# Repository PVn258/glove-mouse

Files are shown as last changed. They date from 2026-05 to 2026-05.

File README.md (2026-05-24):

# Glove Mouse

A wearable BLE HID mouse built on the **XIAO ESP32-C6**, controlled by wrist movement (MPU-6050 gyroscope) and finger sensors (flex + FSR pressure).

---

## Hardware

| Component | Role |
|---|---|
| XIAO ESP32-C6 | Main MCU + BLE |
| MPU-6050 | Gyroscope / accelerometer → cursor movement |
| Flex sensor | Thumb bend → toggle transmission mode |
| FSR (×2) | Left / right click |
| MT3608 boost | Battery → ~4.6 V rail for VIN |
| LM339 (×2) | Analog comparators for flex & FSR digital output |

### Wiring

```
MPU-6050   SDA → GPIO 6   |   SCL → GPIO 7
Flex  DO       → GPIO 4     (thumb bend = transmit mode)
FSR Left  DO   → GPIO 2     (left click)
FSR Right DO   → GPIO 3     (right click)
```

---

## Firmware

### Dependencies (install via Arduino IDE Library Manager)

- **NimBLE-Arduino** by h2zero `≥ 1.4.0`
- **MPU6050** by Electronic Cats

### Board setup

1. Add ESP32 board package URL in Arduino IDE preferences:
   ```
   https://raw.githubusercontent.com/espressif/arduino-esp32/gh-pages/package_esp32_index.json
   ```
2. Install **esp32** by Espressif Systems
3. Select board: **XIAO ESP32C6**

### Usage

1. Flash `glove_mouse/glove_mouse.ino`
2. Open Serial Monitor at **115200 baud**
3. Pair with **"Glove Mouse"** from your host's Bluetooth settings
4. **Bend thumb** → transmission mode (cursor follows wrist, FSR triggers clicks)
5. **Release thumb** → sleep mode (all input paused)

### Tuning parameters

| Constant | Default | Description |
|---|---|---|
| `MAX_MOVE` | 20 | Max pixels per frame (higher = more sensitive) |
| `MAX_DPS` | 200 | Gyro threshold for full speed (°/s) |
| `DEADZONE` | 5 | Dead zone in °/s (higher = less jitter) |
| `CURVE_EXP` | 1.5 | Speed curve exponent (1.0 = linear, >1 = precise low / fast high) |
| `EMA_ALPHA` | 0.25 | Smoothing factor (0.1 = very smooth, 0.4 = responsive) |

---

## Schematic & PCB Design

The circuit was drawn in **EasyEDA Pro** and exported for JLCPCB fabrication.

| File | Description |
|---|---|
| `hardware/ProPrj_Seeed Studio XIAO ESP32C6_2026-05-12_10-11-10_2026-05-13.epro2` | EasyEDA Pro project (editable source) |
| `hardware/SCH_Schematic1_2026-05-14.pdf` | Schematic PDF (quick reference) |

**PCB specs for JLCPCB ordering:**

| Parameter | Value |
|---|---|
| Layers | 2 |
| Board size | 50 × 40 mm |
| Min trace / space | 0.2 mm / 0.2 mm |
| Min via drill | 0.4 mm |
| Surface finish | HASL (lead-free) |

---

## Repository Structure

```
glove_mouse/
└── glove_mouse.ino          Main BLE HID firmware

hardware/
├── *.epro2                  EasyEDA Pro schematic & PCB project
└── *.pdf                    Exported schematic PDF

tests/
├── all_sensors_test/        All sensors combined diagnostic
├── flex_sensor_test/        Flex sensor digital output test
├── mpu6050_test/            MPU-6050 I2C + gyro/accel readout
└── pressure_sensor_test/    FSR pressure sensor test
```

---

## Running the Tests

Each folder under `tests/` is a standalone Arduino sketch.  
Open the `.ino` file in Arduino IDE, select **XIAO ESP32C6**, upload, then open Serial Monitor at **115200 baud**.

| Sketch | What it prints |
|---|---|
| `mpu6050_test` | Accel XYZ + Gyro XYZ raw values |
| `flex_sensor_test` | Digital output of flex comparator (0/1) |
| `pressure_sensor_test` | Digital output of left & right FSR (0/1) |
| `all_sensors_test` | All of the above combined |

---

## License

MIT

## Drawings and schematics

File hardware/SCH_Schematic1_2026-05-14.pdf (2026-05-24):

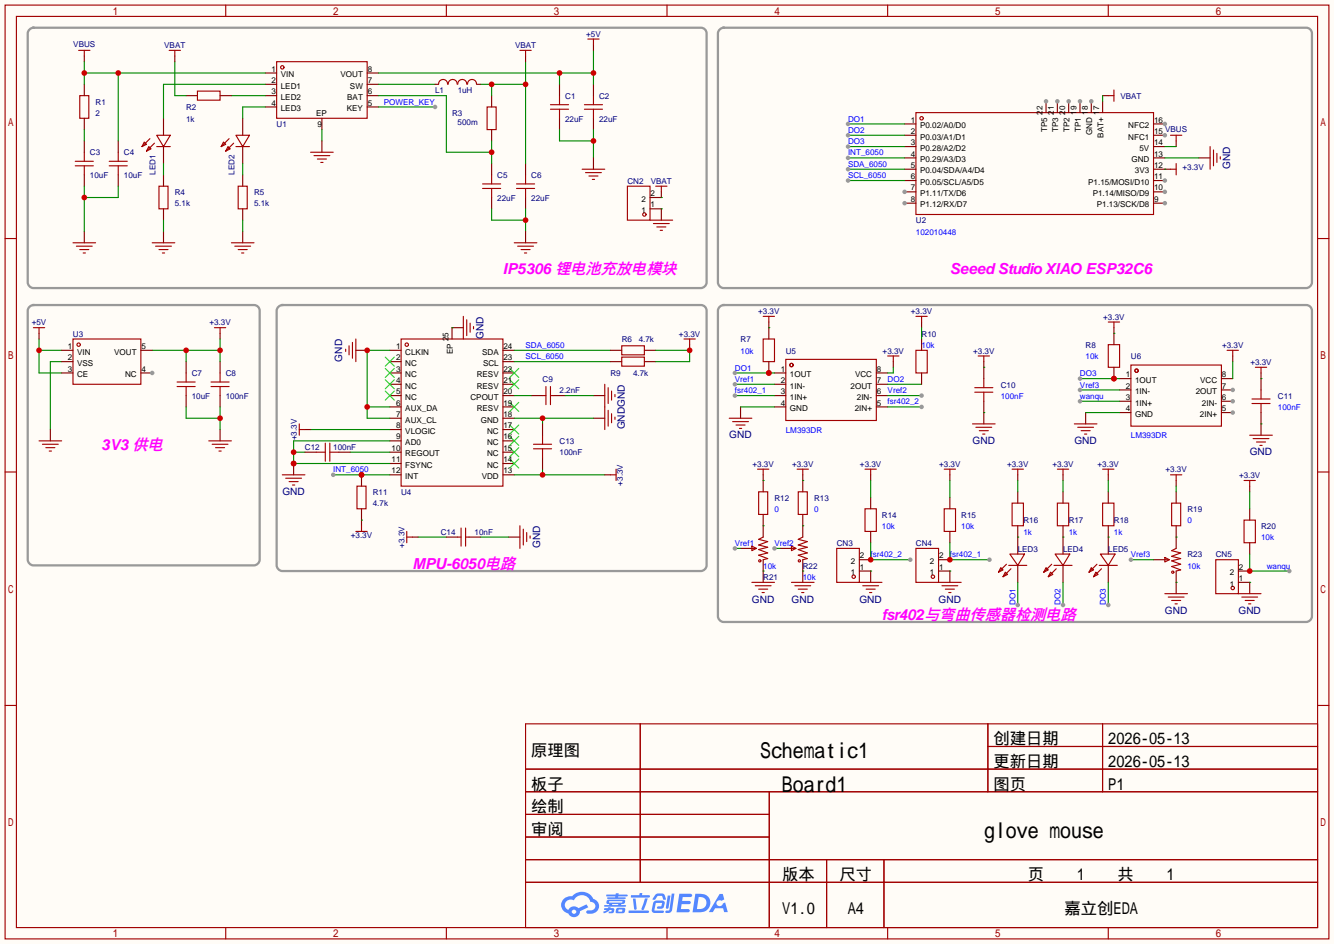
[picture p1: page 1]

P1.14/MISO/D9 10 P1.15/MOSI/D10 11 3V3 12 GND 13 5V 14 NFC1 15 NFC2 16 BAT+ 17 GND ¹⁸

原理图 | Schematic1 | 创建日期 | 2026-05-13

更新日期 | 2026-05-13

板子 | Board1 | 图页 | P1
绘制 | | glove mouse
审阅

V1.0 | A4 | 嘉立创EDA

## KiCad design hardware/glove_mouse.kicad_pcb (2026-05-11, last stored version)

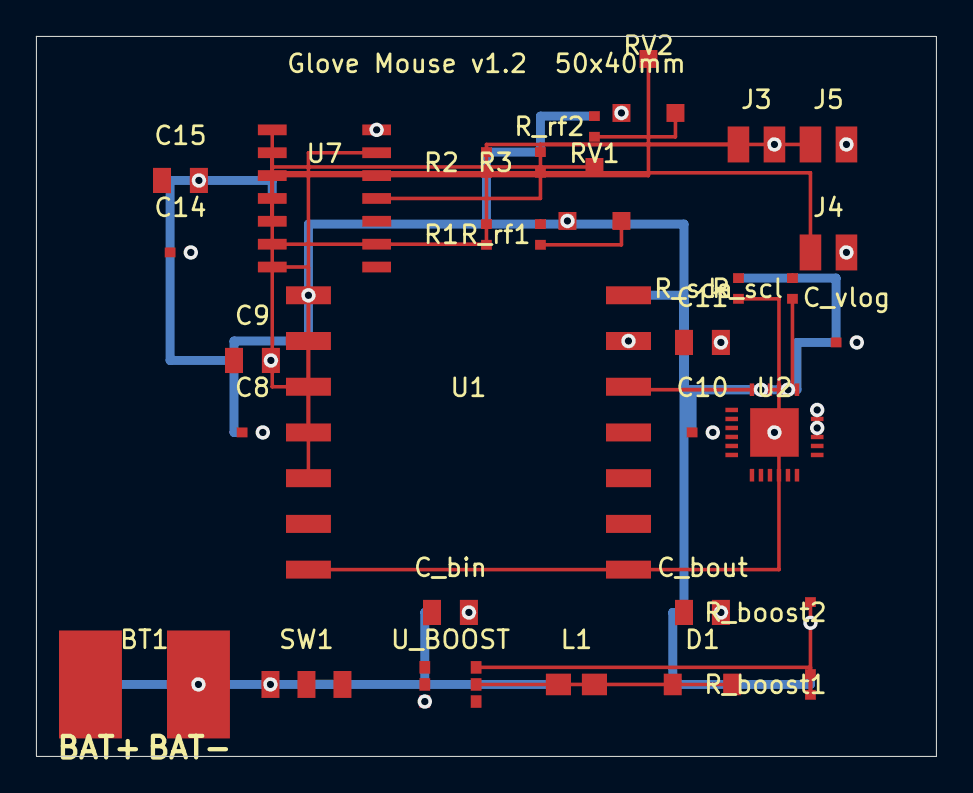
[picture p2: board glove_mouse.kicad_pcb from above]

Board: 2 copper layers, 50.0 x 40.0 mm, 31 parts (0 on the bottom side), 19 nets.

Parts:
BT1: LiPo Battery; BAT-SOLDER
C8, C10, C14: 100nF; C_0402
C9: 22uF; C_0805
C11: 10uF; C_0805
C15: 4.7uF; C_0805
C_bin: 10uF; C_0805
C_bout: 22uF; C_0805
C_vlog: 100nF; C_0402
D1: SS14; SOD-123
J3: Flex; JST-PH-2P
J4: FSR Left; JST-PH-2P
J5: FSR Right; JST-PH-2P
L1: 4.7uH; L_0603
R1: 47k; R_0402
R2, R3: 10k; R_0402
RV1, RV2: 10k Trim; TRIMPOT-3224W
R_boost1: 100k; R_0402
R_boost2: 15k; R_0402
R_rf1, R_rf2: 10k; R_0402
R_scl: 4.7k; R_0402
R_sda: 4.7k; R_0402
SW1: Power SW; SLIDE-SW
U1: XIAO ESP32C6; XIAO-ESP32C6
U2: MPU-6050; QFN-24
U7: LM339; SOP-14
U_BOOST: MT3608; SOT-23-6

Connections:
3V3: C8.1, C9.1, C10.1, C11.1, C14.1, C15.1, C_vlog.1, R1.1, R2.1, R3.1, R_rf1.1, R_rf2.1, R_scl.1, R_sda.1, U1.2, U2.1, U2.6, U7.4
BAT_RAW: BT1.+, SW1.3
BOOST_FB: R_boost1.2, R_boost2.1, U_BOOST.4
BOOST_OUT: C_bout.1, D1.K, R_boost1.1, U1.8
BOOST_SW: D1.A, L1.2, U_BOOST.5
FLEX_DO: U1.5, U7.1
FSR_L_DO: U1.3, U7.7
FSR_R_DO: U1.4, U7.9
GND: BT1.-, C8.2, C9.2, C10.2, C11.2, C14.2, C15.2, C_bin.2, C_bout.2, C_vlog.2, J3.2, J4.2, J5.2, RV1.1, RV2.1, R_boost2.2, SW1.1, U1.1, U1.9, U2.2, U2.5, U2.7, U2.9, U2.25, U7.8, U_BOOST.1
SCL: R_scl.2, U1.10, U2.3
SDA: R_sda.2, U1.7, U2.4
VBAT: C_bin.1, L1.1, SW1.2, U_BOOST.2, U_BOOST.3
VMID_FLEX: J3.1, R1.2, U7.2
VMID_FSR_L: J4.1, R2.2, U7.5
VMID_FSR_R: J5.1, R3.2, U7.11
VREF_FLEX: RV1.W, U7.3
VREF_FLEX_PRE: RV1.3, R_rf1.2
VREF_FSR: RV2.W, U7.6, U7.10
VREF_FSR_PRE: RV2.3, R_rf2.2

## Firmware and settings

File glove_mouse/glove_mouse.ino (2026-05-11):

/*
 * Glove Mouse — BLE HID 鼠标固件
 * 硬件：ESP32C6
 *
 * 接线：
 *   MPU-6050  SDA → GPIO 6  |  SCL → GPIO 7
 *   Flex  DO  → GPIO 4        (拇指弯曲 → 传输模式)
 *   FSR 左DO  → GPIO 2        (左键)
 *   FSR 右DO  → GPIO 3        (右键)
 *
 * 依赖库（Arduino IDE 库管理器安装）：
 *   · NimBLE-Arduino  by h2zero      ≥ 1.4.0
 *   · MPU6050         by Electronic Cats
 *
 * 使用方法：
 *   1. 上传固件，打开串口监视器 (115200 baud)
 *   2. 主机蓝牙搜索并配对 "Glove Mouse"
 *   3. 弯曲拇指 → 传输模式 (光标跟随手腕移动，FSR 触发点击)
 *   4. 松开拇指 → 休眠模式 (停止所有输入)
 *
 * 调参说明：
 *   MAX_MOVE     最大每帧像素（满速时输出，调大更灵敏）
 *   MAX_DPS      对应满速的陀螺仪角速度阈值
 *   DEADZONE     °/s 死区（调大抗手抖，调小响应快）
 *   CURVE_EXP    曲线指数：1.0=线性，>1=低速精准/高速快
 *   EMA_ALPHA    平滑系数：0.1=极平滑，0.4=响应快
 */

#include <Wire.h>
#include <MPU6050.h>
#include <NimBLEDevice.h>
#include <NimBLEServer.h>
#include <NimBLEHIDDevice.h>
#include <HIDTypes.h>

// ── 引脚定义（Seeed XIAO ESP32C6）────────────────────────────
#define SDA_PIN          6
#define SCL_PIN          7
#define PIN_FLEX_DO      17
#define PIN_FSR_LEFT_DO  23
#define PIN_FSR_RIGHT_DO 16

// ── 陀螺仪参数 ────────────────────────────────────────────────
#define GYRO_LSB      131.0f   // ±250°/s 量程对应 LSB 系数
#define DEADZONE      3.0f     // °/s 死区（低于此值=静止）
#define MAX_DPS       80.0f   // °/s，Y轴（俯仰）满速阈值
#define MAX_DPS_X     80.0f   // °/s，X轴（偏航）满速阈值
#define MAX_MOVE      32       // 满速时每帧最大像素位移（X轴）
#define MAX_MOVE_Y    18       // Y轴（上下）满速像素
#define RIGHT_BOOST   1.6f     // X轴向右的额外增益（>1 = 更容易向右）
#define CURVE_EXP     1.4f     // 曲线指数，必须 >1：低速精准/高速快速
                               //   >1 = 凹曲线：10%速→6%输出（精准）
                               //   <1 = 凸曲线：10%速→40%输出（抖动）
#define EMA_ALPHA     0.20f    // EMA 平滑系数（0~1，越小越平滑）

// ── 防抖参数 ──────────────────────────────────────────────────
#define DEBOUNCE_MS   40       // 与传感器测试保持一致

// ── HID 报表描述符（3 按键鼠标 + 相对 X/Y） ──────────────────
// Report ID 1: buttons(1B) + x(1B) + y(1B) = 3 字节
static const uint8_t reportMap[] = {
    USAGE_PAGE(1),       0x01,  // Generic Desktop
    USAGE(1),            0x02,  // Mouse
    COLLECTION(1),       0x01,  // Application
      REPORT_ID(1),      0x01,  //   Report ID = 1
      USAGE(1),          0x01,  //   Pointer
      COLLECTION(1),     0x00,  //   Physical

        // ── 按键：3 位有效 + 5 位填充 ────────────────
        USAGE_PAGE(1),   0x09,  //     Button Page
        USAGE_MINIMUM(1),0x01,  //     Button 1 (左键)
        USAGE_MAXIMUM(1),0x03,  //     Button 3 (中键)
        LOGICAL_MINIMUM(1),0x00,
        LOGICAL_MAXIMUM(1),0x01,
        REPORT_COUNT(1), 0x03,  //     3 按键位
        REPORT_SIZE(1),  0x01,
        HIDINPUT(1),     0x02,  //     Data, Var, Abs
        REPORT_COUNT(1), 0x01,  //     5 位填充
        REPORT_SIZE(1),  0x05,
        HIDINPUT(1),     0x03,  //     Const

        // ── X / Y 相对移动 ────────────────────────────
        USAGE_PAGE(1),   0x01,  //     Generic Desktop
        USAGE(1),        0x30,  //     X
        USAGE(1),        0x31,  //     Y
        LOGICAL_MINIMUM(1),0x81,// -127
        LOGICAL_MAXIMUM(1),0x7F,//  127
        REPORT_SIZE(1),  0x08,
        REPORT_COUNT(1), 0x02,
        HIDINPUT(1),     0x06,  //     Data, Var, Rel

      END_COLLECTION(0),
    END_COLLECTION(0)
};

// ── 全局对象 ──────────────────────────────────────────────────
MPU6050                mpu;
NimBLEServer*          bleServer    = nullptr;
NimBLEHIDDevice*       hidDevice    = nullptr;
NimBLECharacteristic*  inputReport  = nullptr;
volatile bool          bleConnected = false;

// ── Flex 防抖状态（40ms，模式切换用） ────────────────────────
bool     last_flex  = false;
uint32_t flex_ts    = 0;
bool     flex_active = false;
bool     prev_flex_active = false;

// ── 按键状态 ──────────────────────────────────────────────────
// 非对称防抖：按下立即响应，松开需稳定 LEFT_RELEASE_MS 才确认
// 解决 FSR 持续按压时信号抖动导致长按被误判为多次单击的问题
#define LEFT_RELEASE_MS  2   // 左键松开防抖（ms）；短于此的"抬起"视为抖动忽略
#define BTN_DEBOUNCE_MS  1    // 右键双向防抖时间
bool     last_raw_right = false;
uint32_t left_release_ts = 0,  right_db_ts = 0;
bool     deb_left   = false, deb_right  = false;
uint8_t  last_sent_buttons = 0;
bool     btn_dirty  = false;  // 按键状态已变，等待随下一帧发出

// ── EMA 平滑状态（进入传输模式时重置） ──────────────────────
float    ema_x = 0.0f, ema_y = 0.0f;

// ── 发送限速 ─────────────────────────────────────────────────
#define REPORT_INTERVAL_MS  16   // 移动报告 ~60Hz；与 20ms 连接间隔匹配，不积压队列
#define SERIAL_INTERVAL_MS  150  // 串口调试每 150ms 一次
uint32_t last_report_ms = 0;
uint32_t last_serial_ms = 0;

// ─────────────────────────────────────────────────────────────
//  BLE 连接回调
// ─────────────────────────────────────────────────────────────
class MyServerCallbacks : public NimBLEServerCallbacks {
    void onConnect(NimBLEServer* server, NimBLEConnInfo& connInfo) override {
        bleConnected = true;
        // 请求 20-30ms 连接间隔（16-24×1.25ms）
        // 不要请求 7.5ms：Windows 会在 30-60s 后强制重协商 → 重协商期间断流积压 → 卡顿
        // 20ms 是 Windows HID 电源策略的舒适区，不会触发重协商
        server->updateConnParams(connInfo.getConnHandle(), 16, 24, 0, 300);
        Serial.println("[BLE] 已连接！");
    }
    void onDisconnect(NimBLEServer* server, NimBLEConnInfo& connInfo, int reason) override {
        bleConnected = false;
        Serial.println("[BLE] 连接断开，重新广播...");
        server->startAdvertising();
    }
};

// ─────────────────────────────────────────────────────────────
//  工具函数
// ─────────────────────────────────────────────────────────────

// 软件防抖（40ms 稳定确认，与 all_sensors_test 完全一致）
bool debounce(bool raw, bool& last, bool& confirmed, uint32_t& ts) {
    if (raw != last) { last = raw; ts = millis(); }
    if ((millis() - ts) >= DEBOUNCE_MS && raw != confirmed) {
        confirmed = raw;
        return true;
    }
    return false;
}

// 非线性曲线映射：死区→幂次曲线→截断
//   rightBoost：仅对正方向（向右）额外乘以增益，默认 1.0（不增益）
int8_t curveMap(float dps, float maxOut = MAX_MOVE, float maxDps = MAX_DPS,
                float rightBoost = 1.0f) {
    float abs_dps = fabsf(dps);
    if (abs_dps < DEADZONE) return 0;
    float norm = (abs_dps - DEADZONE) / (maxDps - DEADZONE);
    if (norm > 1.0f) norm = 1.0f;
    float output = powf(norm, CURVE_EXP) * maxOut;
    if (dps > 0.0f) {
        output *= rightBoost;
        if (output > 127.0f) output = 127.0f;
        return (int8_t)output;
    }
    return (int8_t)(-output);
}

// 发送 HID 鼠标报告（3 字节：按键 + dX + dY）
// notify(data, len) 直接发送：队列满时丢弃当前帧而非阻塞 loop()
void sendMouseReport(uint8_t buttons, int8_t dx, int8_t dy) {
    if (!bleConnected || inputReport == nullptr) return;
    uint8_t report[3] = { buttons, (uint8_t)dx, (uint8_t)dy };
    inputReport->notify(report, sizeof(report));
}

// ─────────────────────────────────────────────────────────────
//  BLE HID 初始化
// ─────────────────────────────────────────────────────────────
void initBLE() {
    NimBLEDevice::init("Glove Mouse");
    NimBLEDevice::setSecurityAuth(true, true, true);
    NimBLEDevice::setSecurityIOCap(BLE_HS_IO_NO_INPUT_OUTPUT);

    bleServer = NimBLEDevice::createServer();
    bleServer->setCallbacks(new MyServerCallbacks());

    hidDevice   = new NimBLEHIDDevice(bleServer);
    inputReport = hidDevice->getInputReport(1);        // Report ID = 1

    hidDevice->setManufacturer("ESP32C6-Glove");
    hidDevice->setHidInfo(0x00, 0x01);                 // Country=0, Flags=NormallyConnectable

    hidDevice->setReportMap((uint8_t*)reportMap, sizeof(reportMap));
    hidDevice->startServices();

    NimBLEAdvertising* adv = bleServer->getAdvertising();
    adv->setAppearance(HID_MOUSE);
    adv->addServiceUUID(hidDevice->getHidService()->getUUID());
    adv->start();

    Serial.println("[BLE] 广播中... 请在主机蓝牙中搜索 \"Glove Mouse\"");
}

// ─────────────────────────────────────────────────────────────
//  setup
// ─────────────────────────────────────────────────────────────
void setup() {
    Serial.begin(115200);
    delay(500);

    // GPIO 初始化
    // FSR/Flex 比较器 DO 为开漏输出：按下主动拉低，不按时高阻抗
    // 必须启用内部上拉，否则拔掉 USB 后引脚浮空，随机触发按键
    pinMode(PIN_FLEX_DO,      INPUT_PULLUP);
    pinMode(PIN_FSR_LEFT_DO,  INPUT_PULLUP);
    pinMode(PIN_FSR_RIGHT_DO, INPUT_PULLUP);

    // MPU-6050 初始化（400kHz 快速模式，减少 I2C 阻塞时间）
    Wire.begin(SDA_PIN, SCL_PIN);
    Wire.setClock(400000);
    mpu.initialize();
    if (!mpu.testConnection()) {
        Serial.println("[ERR] MPU-6050 连接失败！检查 SDA/SCL 接线后重启。");
        while (true) delay(1000);
    }
    Serial.println("[OK]  MPU-6050 就绪");

    // BLE HID 初始化
    initBLE();

    Serial.println("=== Glove Mouse 固件就绪 ===");
    Serial.println("弯曲拇指 → 传输模式 | 松开拇指 → 休眠模式");
    Serial.println("---");
}

// ─────────────────────────────────────────────────────────────
//  loop  (100 Hz)
// ─────────────────────────────────────────────────────────────
void loop() {
    uint32_t now = millis();

    // ── 1. 读取传感器 ────────────────────────────────────────
    bool raw_flex  = (digitalRead(PIN_FLEX_DO)      == LOW);
    bool raw_left  = (digitalRead(PIN_FSR_LEFT_DO)  == LOW);
    bool raw_right = (digitalRead(PIN_FSR_RIGHT_DO) == LOW);

    // ── 2. Flex 防抖（40ms，仅用于模式切换） ─────────────────
    debounce(raw_flex, last_flex, flex_active, flex_ts);

    // ── 3. 按键通道（与 flex 完全独立） ──────────────────────────
    // 左键：非对称防抖
    //   按下 → 立即确认（不错过点击）
    //   松开 → 需稳定 LEFT_RELEASE_MS 才确认（忽略持续按压中的短暂抖动）
    if (raw_left) {
        deb_left = true;           // 按下：立即
        left_release_ts = 0;       // 重置松开计时
    } else if (deb_left) {         // 原本是按下，现在信号消失
        if (left_release_ts == 0) left_release_ts = now;
        if (now - left_release_ts >= LEFT_RELEASE_MS) deb_left = false;
    }

    // 右键：1ms 双向防抖
    if (raw_right != last_raw_right){ last_raw_right = raw_right; right_db_ts = now; }
    if ((now - right_db_ts) >= BTN_DEBOUNCE_MS) deb_right = raw_right;

    uint8_t buttons = (deb_left ? 0x01 : 0x00) | (deb_right ? 0x02 : 0x00);
    if (buttons != last_sent_buttons) {
        last_sent_buttons = buttons;
        btn_dirty = true;   // 标记待发，不立即发——避免用 0,0 打断正在进行的移动
    }

    // ── 4. 传输模式：陀螺仪移动（独立限速） ──────────────────
    if (flex_active) {
        if (!prev_flex_active) { ema_x = 0.0f; ema_y = 0.0f; }  // 入场重置

        if (now - last_report_ms >= REPORT_INTERVAL_MS) {
            // 断流保护：若距上次发送超 80ms（重连/干扰后），重置 EMA 并跳过本帧
            // 避免积压的陈旧运动数据在恢复时一次性涌出导致主机卡顿
            if (now - last_report_ms > 80) {
                ema_x = 0.0f; ema_y = 0.0f;
                last_report_ms = now;
                prev_flex_active = flex_active;
                return;
            }
            last_report_ms = now;

            int16_t ax, ay, az, gx, gy, gz;
            mpu.getMotion6(&ax, &ay, &az, &gx, &gy, &gz);

            float combined_x = (gy - gz) / GYRO_LSB;  // 小臂旋转 + 手腕侧弯
            float gx_dps     = gx / GYRO_LSB;

            ema_x = EMA_ALPHA * combined_x + (1.0f - EMA_ALPHA) * ema_x;
            ema_y = EMA_ALPHA * gx_dps     + (1.0f - EMA_ALPHA) * ema_y;

            int8_t mx = curveMap(-ema_x, MAX_MOVE,   MAX_DPS_X, RIGHT_BOOST);
            int8_t my = curveMap(-ema_y, MAX_MOVE_Y, MAX_DPS);

            // 有移动 或 按键状态待发 → 合并进同一帧，消除按键触发时的移动停顿
            if (mx || my || btn_dirty) {
                sendMouseReport(last_sent_buttons, mx, my);
                btn_dirty = false;
            }

            // 串口调试（Serial.printf 在此处调用，已在 BLE 发送之后，不影响发送时序）
            if (now - last_serial_ms >= SERIAL_INTERVAL_MS) {
                last_serial_ms = now;
                Serial.printf("[传输] 左:%s 右:%s | dX:%4d dY:%4d\n",
                    deb_left ? "▼" : "○", deb_right ? "▼" : "○",
                    (int)mx, (int)my);
            }
        }
    }

    // ── 5. 非传输模式下：若按键状态待发则立即发（无移动帧可搭载） ──
    if (!flex_active && btn_dirty) {
        sendMouseReport(last_sent_buttons, 0, 0);
        btn_dirty = false;
    }

    // ── 6. 模式切换：退出传输时发一次零移动确保干净 ──────────
    if (prev_flex_active && !flex_active) {
        sendMouseReport(last_sent_buttons, 0, 0);
        Serial.println("[休眠]");
    }

    prev_flex_active = flex_active;
}

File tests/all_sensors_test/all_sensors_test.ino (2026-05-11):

/*
 * 三传感器综合测试草图
 *
 * 在不连接蓝牙主机的情况下，验证所有传感器读数和状态逻辑正确。
 * 所有引脚、极性、防抖逻辑与主程序 glove_mouse.ino 完全同步。
 *
 * 接线汇总（与主程序一致）：
 *   MPU-6050  SDA → GPIO 0  |  SCL → GPIO 1
 *   Flex DO   → GPIO 17
 *   FSR 左DO  → GPIO 23  |  FSR 右DO → GPIO 16
 *
 * 依赖库：MPU6050 by Electronic Cats
 *
 * Serial Monitor 输出示例：
 *   [传输] 左:[按下] 右:[----] | dX:  12 dY:  -3  (EMA X: 8.2  Y:-2.1)
 *   [休眠] 左:[----] 右:[----] | 静止
 */

#include <Wire.h>
#include <MPU6050.h>

// ── 引脚定义（与主程序完全一致） ──────────────────────────────
#define SDA_PIN          0
#define SCL_PIN          1
#define PIN_FLEX_DO      17
#define PIN_FSR_LEFT_DO  23
#define PIN_FSR_RIGHT_DO 16

// ── 陀螺仪参数（与主程序完全一致） ────────────────────────────
#define GYRO_LSB    131.0f
#define DEADZONE    3.0f
#define MAX_DPS     80.0f
#define MAX_DPS_X   80.0f
#define MAX_MOVE    32
#define MAX_MOVE_Y  18
#define RIGHT_BOOST 1.6f
#define CURVE_EXP   1.4f
#define EMA_ALPHA   0.20f

// ── 防抖参数（与主程序完全一致） ──────────────────────────────
#define FLEX_DEBOUNCE_MS  40    // Flex 模式切换防抖
#define LEFT_RELEASE_MS   25    // 左键松开防抖（非对称）
#define BTN_DEBOUNCE_MS   1     // 右键双向防抖

MPU6050 mpu;

// ── Flex 防抖状态 ─────────────────────────────────────────────
bool     last_flex   = false;
bool     flex_active = false;
uint32_t flex_ts     = 0;

// ── 左键非对称防抖状态 ────────────────────────────────────────
bool     deb_left        = false;
uint32_t left_release_ts = 0;

// ── 右键双向防抖状态 ──────────────────────────────────────────
bool     last_raw_right = false;
bool     deb_right      = false;
uint32_t right_db_ts    = 0;

// ── EMA 状态 ──────────────────────────────────────────────────
float ema_x = 0.0f, ema_y = 0.0f;
bool  prev_flex = false;

// ── 通用防抖（Flex 使用） ─────────────────────────────────────
bool debounce(bool raw, bool& last, bool& confirmed, uint32_t& ts) {
    if (raw != last) { last = raw; ts = millis(); }
    if ((millis() - ts) >= FLEX_DEBOUNCE_MS && raw != confirmed) {
        confirmed = raw;
        return true;
    }
    return false;
}

// ── 与主程序完全相同的曲线映射 ───────────────────────────────
int8_t curveMap(float dps, float maxOut, float maxDps, float rightBoost = 1.0f) {
    float abs_dps = fabsf(dps);
    if (abs_dps < DEADZONE) return 0;
    float norm = (abs_dps - DEADZONE) / (maxDps - DEADZONE);
    if (norm > 1.0f) norm = 1.0f;
    float output = powf(norm, CURVE_EXP) * maxOut;
    if (dps > 0.0f) {
        output *= rightBoost;
        if (output > 127.0f) output = 127.0f;
        return (int8_t)output;
    }
    return (int8_t)(-output);
}

void setup() {
    Serial.begin(115200);
    delay(500);

    // INPUT_PULLUP：比较器/Flex DO 为开漏，不上拉会浮空误触
    pinMode(PIN_FLEX_DO,      INPUT_PULLUP);
    pinMode(PIN_FSR_LEFT_DO,  INPUT_PULLUP);
    pinMode(PIN_FSR_RIGHT_DO, INPUT_PULLUP);

    Wire.begin(SDA_PIN, SCL_PIN);
    Wire.setClock(400000);   // 400kHz，与主程序一致

    mpu.initialize();
    if (!mpu.testConnection()) {
        Serial.println("[ERR] MPU-6050 连接失败！检查 SDA->GPIO0 / SCL->GPIO1 接线后重启。");
        while (true) delay(1000);
    }

    Serial.println("=== 综合传感器测试（与主程序逻辑完全一致）===");
    Serial.println("弯曲拇指(GPIO17 LOW) → 传输模式 | 左键(GPIO23 LOW) | 右键(GPIO16 LOW)");
    Serial.println("---");
}

void loop() {
    uint32_t now = millis();

    // ── 1. 读取原始状态（LOW = 触发，与主程序一致） ───────────
    bool raw_flex  = (digitalRead(PIN_FLEX_DO)      == LOW);
    bool raw_left  = (digitalRead(PIN_FSR_LEFT_DO)  == LOW);
    bool raw_right = (digitalRead(PIN_FSR_RIGHT_DO) == LOW);

    // ── 2. Flex 防抖（40ms） ──────────────────────────────────
    debounce(raw_flex, last_flex, flex_active, flex_ts);

    // ── 3. 左键非对称防抖（按下立即，松开稳定 25ms） ─────────
    if (raw_left) {
        deb_left        = true;
        left_release_ts = 0;
    } else if (deb_left) {
        if (left_release_ts == 0) left_release_ts = now;
        if (now - left_release_ts >= LEFT_RELEASE_MS) deb_left = false;
    }

    // ── 4. 右键双向防抖（1ms） ────────────────────────────────
    if (raw_right != last_raw_right) { last_raw_right = raw_right; right_db_ts = now; }
    if ((now - right_db_ts) >= BTN_DEBOUNCE_MS) deb_right = raw_right;

    // ── 5. 陀螺仪 + 光标仿真（传输模式才计算） ───────────────
    int8_t mx = 0, my = 0;
    float  cur_ema_x = 0, cur_ema_y = 0;

    if (flex_active) {
        if (!prev_flex) { ema_x = 0.0f; ema_y = 0.0f; }  // 入场重置

        int16_t ax, ay, az, gx, gy, gz;
        mpu.getMotion6(&ax, &ay, &az, &gx, &gy, &gz);

        // 与主程序完全相同的轴融合
        float combined_x = (gy - gz) / GYRO_LSB;
        float gx_dps     = gx / GYRO_LSB;

        ema_x = EMA_ALPHA * combined_x + (1.0f - EMA_ALPHA) * ema_x;
        ema_y = EMA_ALPHA * gx_dps     + (1.0f - EMA_ALPHA) * ema_y;

        mx = curveMap(-ema_x, MAX_MOVE,   MAX_DPS_X, RIGHT_BOOST);
        my = curveMap(-ema_y, MAX_MOVE_Y, MAX_DPS);

        cur_ema_x = ema_x;
        cur_ema_y = ema_y;
    }

    prev_flex = flex_active;

    // ── 6. 输出 ───────────────────────────────────────────────
    Serial.print(flex_active ? "[传输] " : "[休眠] ");

    Serial.print("左:");
    Serial.print(deb_left  ? "[按下]" : "[----]");
    Serial.print("(原始:");
    Serial.print(raw_left  ? "LOW" : "HI ");
    Serial.print(")  右:");
    Serial.print(deb_right ? "[按下]" : "[----]");
    Serial.print("(原始:");
    Serial.print(raw_right ? "LOW" : "HI ");
    Serial.print(")");

    if (flex_active) {
        Serial.print("  |  dX:");
        if (mx >= 0) Serial.print(" ");
        Serial.print((int)mx);
        Serial.print(" dY:");
        if (my >= 0) Serial.print(" ");
        Serial.print((int)my);
        Serial.print("  (EMA X:");
        Serial.print(cur_ema_x, 1);
        Serial.print(" Y:");
        Serial.print(cur_ema_y, 1);
        Serial.print(")");
    } else {
        Serial.print("  |  静止（弯曲拇指进入传输模式）");
    }

    Serial.println();
    delay(50);
}

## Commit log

2026-05-11 Initial commit: ESP32-C6 glove mouse hardware & firmware
    - hardware/: KiCad 8 schematic + PCB (50×40mm, 2-layer), EasyEDA JSON,
    BOM for JLCPCB, and Python generator scripts
    - glove_mouse/: Arduino firmware (MPU-6050 IMU, flex/FSR sensors, BLE HID)
    - tests/: per-sensor test sketches
    - docs/: project report
    [bom_jlcpcb.csv, glove_mouse.kicad_pcb, glove_mouse.kicad_sch]
2026-05-11 Trim repo to firmware + tests only; add README
    - Remove hardware/ (KiCad/EasyEDA design files) and docs/ from tracking
    - Add README with wiring, usage, tuning params, and test guide
    - Update .gitignore to exclude hardware/ and docs/ going forward
    [bom_jlcpcb.csv, glove_mouse.kicad_pcb, glove_mouse.kicad_sch]
2026-05-24 Add EasyEDA Pro schematic and PDF to hardware/
    - hardware/ProPrj_*.epro2: editable EasyEDA Pro project for XIAO ESP32C6 board
    - hardware/SCH_Schematic1_2026-05-14.pdf: exported schematic for quick reference
    - Updated .gitignore to track *.epro2 and *.pdf inside hardware/
    - Updated README with schematic/PCB section and JLCPCB ordering specs
